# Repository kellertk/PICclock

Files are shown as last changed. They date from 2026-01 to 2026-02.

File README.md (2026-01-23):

# PICclock

Variable-frequency clock generator using PIC16F18344 hardware NCO.

See [src/README.md](src/README.md) and [hardware/README.md](hardware/README.md) for details.

## Features

- 1 Hz to 1 MHz output with 50% duty cycle
- Hardware NCO for 12+ Hz (zero CPU overhead)
- Software timing for 1-11 Hz
- Logarithmic frequency sweep via potentiometer
- Step mode for single pulses

## Building

1. Run the configure script:
   - Windows: `.\configure.ps1`
   - Linux/macOS: `./configure`

2. Build: `make`

3. Flash: `make flash`

## Requirements

- Microchip XC8 compiler
- MPLAB X IDE (for IPE and DFP)
- PICkit 5 (or compatible programmer)
- PIC16F1xxxx_DFP device family pack

## License

This project is intentionally available under a restrictive license: CC BY-NC-SA.
Commercial use of this work is not permitted without prior agreement. Please contact
me if you need alternate licensing terms. See [LICENSE.txt](LICENSE.txt) for details.

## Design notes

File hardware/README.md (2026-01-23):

# PICclock Hardware

## Overview

**Architecture:**
```
                          ACTIVE CLOCK OUTPUT
                                  ^
                                  |
                          +-------+-------+
                          |U3: EL7232CNZ  |
                          | Line Driver   |
                          +-------+-------+
                                  |
                          +-------+-------+
                          |U2: 74HC00     |
                          | (VAR/HS MUX)  |
                          +---+-------+---+
                              |       |
                +-------------+       +-------------+
                |                                   |
        VARIABLE CLOCK                        HIGH-SPEED
        (PIC RB6 NCO output)                  OSCILLATOR
                |                                (Y2)
          +-----+-----+
          |   PIC     |
          |   U1      |
          +-----+-----+
           |  |  |  |  |
       [POT][BTN][SW1][SW2]
```

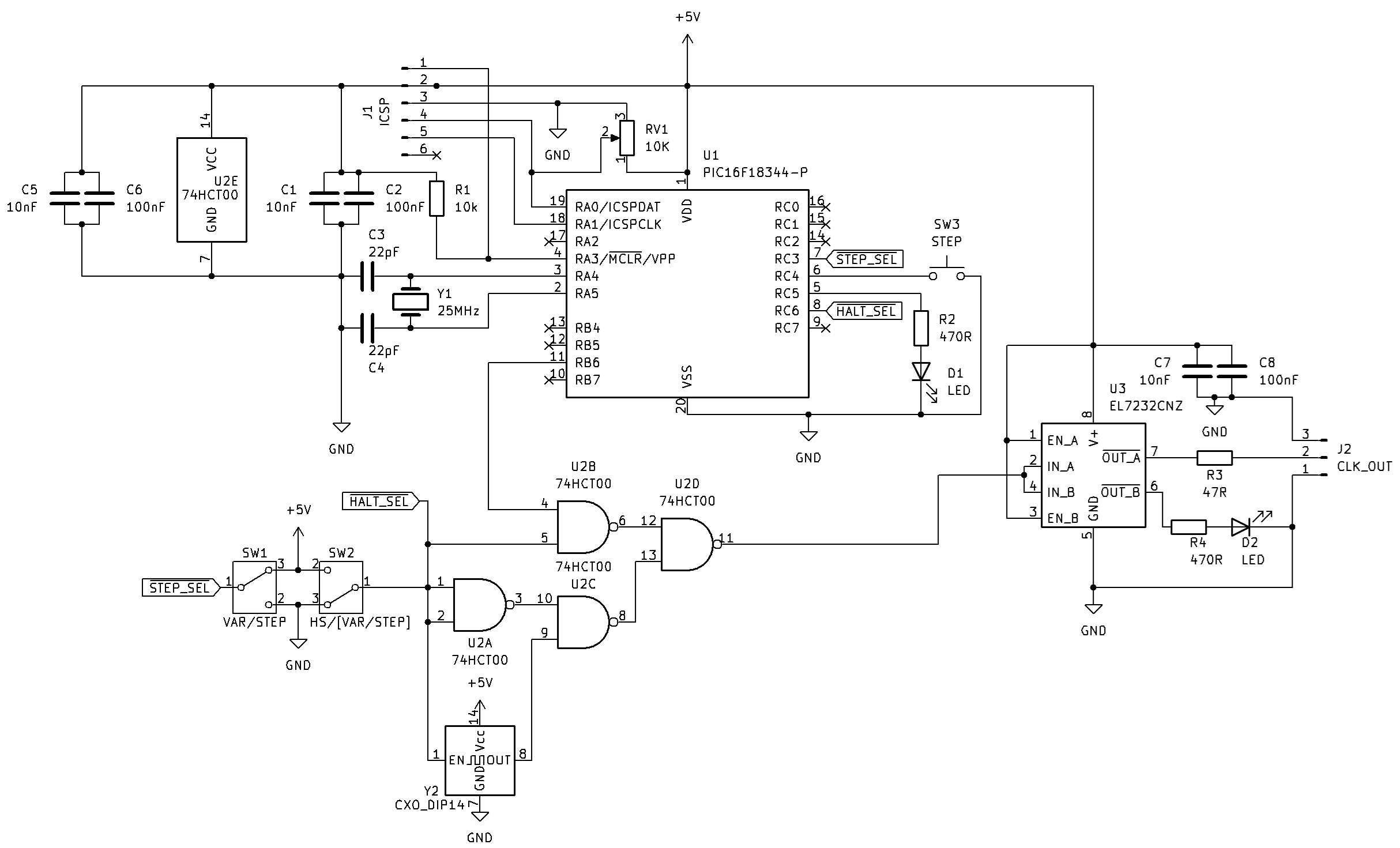
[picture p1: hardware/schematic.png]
PICclock Schematic


**Clock Modes:**
- **Variable**: Hybrid NCO/software clock from PIC (1 Hz - 1 MHz), 50% duty cycle
- **Step**: Single pulse per button press (handled by PIC, debounced in software)
- **High-Speed**: External oscillator bypass

**Frequency Control:** PIC reads potentiometer via ADC. Hardware NCO generates clock for 12 Hz - 1 MHz; software timing handles 1 Hz - 11 Hz. Frequency accuracy inherits PIC crystal stability (typically ±50 ppm).

**Output Driver:** EL7232CNZ line driver buffers clock output.

**Variable Frequency Range:** 1 Hz to 1 MHz (hybrid NCO/software, 50% duty cycle)

---

## Components

### ICs

| Ref | Part | Function |
|-----|---|---|
| U1 | PIC16F18344-I/P | Clock generation (NCO + software timing) |
| U2 | 74HC00 | Quad NAND (var/HS mux) |
| U3 | EL7232CNZ | Line driver |

### Oscillators

| Ref | Part | Function |
|-----|---|---|
| Y1 | 24 MHz crystal | PIC clock |
| Y2 | Oscillator module (w/enable) | High-speed clock (user-selected frequency) |

### Switches & Controls

| Ref | Part | Function |
|-----|---|---|
| SW1 | SPDT slide | Variable/Step select |
| SW2 | SPDT slide | Variable/High-Speed select |
| SW3 | Pushbutton (NO) | Step pulse trigger |
| VR1 | 10K pot | Frequency control |

### Passive Components

| Ref | Value | Function |
|-----|---|---|
| C1 | 10nF | U1 bypass |
| C2 | 100nF | U1 bypass |
| C3, C4 | 22pF | Y1 load caps |
| C5 | 10nF | U2 bypass |
| C6 | 100nF | U2 bypass |
| C7 | 10nF | U3 bypass |
| C8 | 100nF | U3 bypass |
| R1 | 10K | MCLR pull-up |
| R2 | 330Ω | Debug LED current limit |
| R3 | 47Ω | Clock output series resistor |
| R4 | 470Ω | Clock LED current limit |
| LED1 | LED | Debug indicator |
| LED2 | LED | Clock indicator |

---

## Signal Reference

| Signal | Description |
|---|---|
| VAR_CLK | Variable clock from PIC (RB6 NCO1), active low |
| HS_CLK | High-speed external oscillator |
| STEP_SEL | Step mode select (SW1, active low = step) |
| HALT_SEL | High-speed mode select (SW2, active low = high-speed) |
| CLK_OUT | Final clock output (from U3) |

---

## U1: PIC16F18344-I/P (DIP-20)

```
                    +------------+
              VDD --|1         20|-- VSS (GND)
         RA5/OSC1 --|2         19|-- RA0/AN0 <-- VR1 (POT)
         RA4/OSC2 --|3         18|-- RA1/ICSPCLK
     MCLR/VPP/RA3 --|4         17|-- RA2 -x
DEBUG_LED <-- RC5 --|5         16|-- RC0 -x
      SW3 --> RC4 --|6         15|-- RC1 -x
      SW1 --> RC3 --|7         14|-- RC2 -x
      SW2 --> RC6 --|8         13|-- RB4 -x
           x- RC7 --|9         12|-- RB5 -x
           x- RB7 --|10        11|-- RB6 --> VAR_CLK
                    +------------+
```

| Pin | Name | Signal | To |
|-----|---|---|----|
| 1 | VDD | +5V | +5V, J1-2 |
| 2 | RA5/OSC1 | XTAL | Y1, C1 |
| 3 | RA4/OSC2 | XTAL | Y1, C2 |
| 4 | MCLR/VPP/RA3 | MCLR | +5V via R1, J1-1 |
| 5 | RC5 | DEBUG_LED | LED, current limit resistor to GND |
| 6 | RC4 | STEP_BTN | SW3 (internal pull-up) |
| 7 | RC3 | STEP_SEL | SW1 common |
| 8 | RC6 | HALT_SEL | SW2 common |
| 9 | RC7 | - | nc |
| 10 | RB7 | - | nc |
| 11 | RB6 | VAR_CLK | U2-4 (mux input) |
| 12 | RB5 | - | nc |
| 13 | RB4 | - | nc |
| 14 | RC2 | - | nc |
| 15 | RC1 | - | nc |
| 16 | RC0 | - | nc |
| 17 | RA2 | - | nc |
| 18 | RA1 | ICSPCLK | J1-5 |
| 19 | RA0/AN0 | POT | VR1 wiper, J1-4 (ICSPDAT) |
| 20 | VSS | GND | GND, J1-3 |

---

## U2: 74HC00

```
74HC00 (DIP-14)
       +-------+
    1A-|1    14|-VCC
    1B-|2    13|-4B
    1Y-|3    12|-4A
    2A-|4    11|-4Y
    2B-|5    10|-3B
    2Y-|6     9|-3A
   GND-|7     8|-3Y
       +-------+
```

| Pin | Signal | To |
|-----|---|----|
| 1 | 1A | SW2 |
| 2 | 1B | SW2 |
| 3 | 1Y | S̄ → U2-10 |
| 4 | 2A | VAR_CLK (from U1-11, PIC RB6) |
| 5 | 2B | SW2 |
| 6 | 2Y | U2-12 |
| 7 | GND | GND |
| 8 | 3Y | U2-13 |
| 9 | 3A | HS_CLK (from Y2-3) |
| 10 | 3B | U2-3 (S̄) |
| 11 | 4Y | MUX_OUT → U3-2 (line driver input) |

**Mux Truth Table:**

| SW2 | Output |
|-----|---|
| GND (low) | HS_CLK (high-speed oscillator) |
| +5V (high) | VAR_CLK (PIC NCO/software clock or step pulse) |

---

## U3: EL7232CNZ Line Driver

Dual inverting line driver with 3-state outputs. Enable pins are active high.

```
EL7232CNZ (DIP-8)
        +-------+
    ENA-|1     8|-V+
   A IN-|2     7|-A OUT
    ENB-|3     6|-B OUT
   B IN-|4     5|-GND
        +-------+
```

| Pin | Signal | To |
|-----|---|----|
| 1 | ENA | +5V (always enabled) |
| 2 | A IN | MUX_OUT (from U2-11), U3-4 |
| 3 | ENB | +5V (always enabled) |
| 4 | B IN | U3-2 (A IN) |
| 5 | GND | GND |
| 6 | B OUT | LED2 anode, R4 to GND |
| 7 | A OUT | R3 → J2-1 |
| 8 | V+ | +5V |

**Note:** Inverting driver. Channel A drives clock output. Channel B mirrors channel A to drive clock indicator LED.

## Y2: High-Speed Oscillator Module

Standard 4-pin metal can oscillator with active-low enable.

```
     +---------+
     |   Y2    |
     | OSC CAN |
     +---------+
      1  2  3  4
      |  |  |  |
    /EN GND OUT VCC
      |      |   |
     SW2   U2-9 +5V
```

| Pin | Signal | To |
|-----|---|----|
| 1 | /EN | SW2 common (active low) |
| 2 | GND | GND |
| 3 | OUT | HS_CLK → U2-9 |
| 4 | VCC | +5V |

When SW2=GND (halt/HS mode): oscillator enabled, outputs HS_CLK.  
When SW2=+5V (run mode): oscillator disabled, PIC generates clock.

## SW1: SPDT Slide Switch (Variable/Step Select)

```
SW1 (Variable/Step):
  +5V ──[1]
           ├── STEP_SEL → U1-7 (PIC RC3)
  GND ──[2]
```

- **Position 1 (+5V):** Variable mode - PIC generates continuous clock based on pot
- **Position 2 (GND):** Step mode - PIC waits for button press, outputs single pulse

---

## SW2: SPDT Slide Switch (Variable/High-Speed Select)

```
SW2 (Var / High-Speed):
  +5V ──[1]
           ├──┬── HALT_SEL → U1-8 (PIC RC6)
  GND ──[2]   ├── SEL   → U2-1, U2-2, U2-5
              └── /EN   → Y2-1 (oscillator enable, active low)
```

- **Position 1 (+5V):** Variable/Step mode - PIC generates clock, Y2 disabled
- **Position 2 (GND):** High-speed mode - PIC halted, Y2 enabled

---

## SW3: Step Button

Normally-open momentary pushbutton. PIC internal pull-up enabled, debounced in software.

```
U1-6 (PIC RC4) ──┬── [SW3] ── GND
                  │
            (internal pull-up)
```

In step mode (SW1=low), pressing SW3 causes PIC to output a single clock pulse.

---

| 1 | MCLR/VPP | U1-4 (RA3), R1 to +5V |
| 2 | VDD | +5V |
| 3 | VSS | GND |
| 4 | ICSPDAT | U1-19 (RA0) |
| 5 | ICSPCLK | U1-18 (RA1) |

---

## J2: Clock Output (1x2)

| Pin | Signal | To |
|-----|---|----|
| 1 | CLK_OUT | R3 ← U3-7 (EL7232 A OUT) |

## BOM

### ICs
| Ref | Part | Package | Qty |
|-----|---|---|-----|
| U1 | PIC16F18344-I/P | DIP-20 | 1 |
| U2 | 74HC00 | DIP-14 | 1 |
| U3 | EL7232CNZ | DIP-8 | 1 |
| U4 | LM3914 | DIP-18 | 1 |
| Q1 | 2N7000 | TO-92 | 1 |
| Y2 | Oscillator module | DIP-8/14 | 1 |

### Crystal & Capacitors
| Ref | Value | Qty | Function |
|-----|---|-----|---|
| Y1 | 24 MHz | 1 | PIC crystal |
| C1, C2 | 22pF | 2 | Y1 load caps |
| C3, C4, C5, C6 | 100nF | 4 | Decoupling |

### Resistors
| Ref | Value | Qty | Function |
|-----|---|-----|---|
| R1 | 10K | 1 | MCLR pull-up |

### Switches & Controls
| Ref | Part | Qty | Function |
|-----|---|-----|---|
| VR1 | 10K pot | 1 | Frequency control |
| SW1 | SPDT slide | 1 | Var/Step select |
| SW2 | SPDT slide | 1 | (Var+Step)/HS select |
| SW3 | Pushbutton NO | 1 | Step trigger |

### Connectors
| Ref | Part | Qty | Function |
|-----|---|-----|---|
| J1 | 1x5 header | 1 | ICSP |
| J2 | 1x2 header | 1 | Clock output |

---

## Data Flow

### Variable Clock Mode (SW1=+5V, SW2=+5V):
1. Y2 oscillator disabled (/EN=high)
2. PIC sees HALT_SEL=high on RC6, STEP_SEL=high on RC3
3. PIC reads potentiometer on AN0
4. PIC generates clock on RB6 using NCO (≥12 Hz) or software timing (<12 Hz)
5. U2 NAND mux passes VAR_CLK
6. U3 line driver buffers output
7. CLK_OUT = hybrid NCO/software clock (1 Hz to 1 MHz)

### Step Mode (SW1=GND, SW2=+5V):
1. Y2 oscillator disabled (/EN=high)
2. PIC sees HALT_SEL=high on RC6, STEP_SEL=low on RC3
3. PIC waits for button press on RC4 (debounced in software)
4. On press: PIC outputs single pulse on RB6
5. U2 mux passes pulse to output
6. CLK_OUT = single step pulse

### High-Speed Mode (SW2=GND):
1. Y2 oscillator enabled (/EN=low)
2. PIC sees HALT_SEL=low on RC6, holds RB6 low, LED off
3. U2 mux selects HS_CLK
4. U3 line driver buffers output
5. CLK_OUT = high-speed oscillator frequency
6. SW1 position ignored

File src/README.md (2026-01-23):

# PICclock Firmware Design

## Overview

Generates a variable-frequency clock output using a hybrid NCO/software approach.  
Output range: 1 Hz to 1 MHz on RB6 with 50% duty cycle.

**Timing Methods:**
- **NCO mode (12 Hz - 1 MHz):** Hardware NCO generates clock with zero CPU overhead
- **Software mode (1 Hz - 11 Hz):** Delay loops for sub-NCO frequencies

Frequency accuracy inherits from the PIC's 24 MHz crystal (typically ±50 ppm).

## Hardware Interface

| Function | Pin  | Description |
|---|---|---|
| Crystal | RA4/5| 24 MHz external crystal |
| ADC Input | RA0  | Potentiometer (0-5V) |
| Clock Output | RB6  | NCO1 output, active low (drives EL7232CNZ) |
| Debug LED | RC5  | Status indicator |
| Halt Select | RC6  | High-speed mode (SW2, active low) |
| Step Button | RC4  | Step pulse trigger (SW3) |
| Step Select | RC3  | Step mode select (SW1, active low) |
| ICSP | RA0/1| Programming interface |

## Timing Analysis

PIC16F18344 @ 24 MHz:
- NCO clock = Fosc = 24 MHz
- NCO resolution = 20 bits (2^20 = 1,048,576)

**NCO Frequency Formula:**
```
F_out = (Fosc × NCO_INC) / 2^21
F_out = (24,000,000 × NCO_INC) / 2,097,152
```

**NCO Increment Range:**

| NCO_INC | Frequency |
|---|---|
| 1 | 11.4 Hz |
| 87,381  | 1 MHz |

**Software Mode Formula:**
```
F_out = Fosc / (2 × half_period_cycles)
F_out = 24,000,000 / (2 × half_period)
```

## Modules

### main.c

Application entry point with hybrid clock generation.

| Function | Purpose |
|---|---|
| `adc_init` | Configure AN0 with Fosc/64 clock |
| `adc_read` | Return 8-bit ADC result |
| `nco_init` | Configure NCO1 for FDC mode output |
| `nco_set_increment`| Update NCO frequency |
| `nco_connect` | Route NCO1 to RB6 via PPS |
| `nco_disconnect` | Disconnect NCO, use GPIO |
| `nco_stop` | Disable NCO output |
| `output_step_pulse`| Generate single step pulse |
| `button_pressed` | Debounced button read |
| `main` | Mode detection and clock generation  |

### freq_table.h

Combined lookup table mapping ADC values (0-255) to frequency settings.

| Data | Purpose |
|---|---|
| `freq_table[]` | 256 entries: software half-periods or NCO increments |

Bit 31 indicates mode:
- Bit 31 = 1: Software mode, bits 0-23 = half-period in cycles
- Bit 31 = 0: NCO mode, bits 0-19 = NCO increment value

Logarithmically spaced (1 Hz to 1 MHz) for perceptually uniform control feel.

## Main Loop

1. Check mode switches (active low):
   - RC6 (Halt): Hold output low, LED off
   - RC3 (Step): Wait for button, output single pulse
2. If resuming from halt/step:
   - Re-read ADC and reconfigure mode
3. If software mode (freq < 12 Hz):
   - Generate clock with delay loops
   - Check for mode/frequency changes during delays
4. If NCO mode (freq ≥12 Hz):
   - NCO runs autonomously
   - Poll ADC for frequency changes

## Configuration Bits

| Setting | Value | Reason |
|---|---|---|
| FOSC | HS | 24 MHz external crystal |
| WDTE | OFF | No watchdog needed |
| PWRTE | OFF | Power-up timer disabled |
| BOREN | ON | Brown-out protection |
| CP | OFF | No code protection |

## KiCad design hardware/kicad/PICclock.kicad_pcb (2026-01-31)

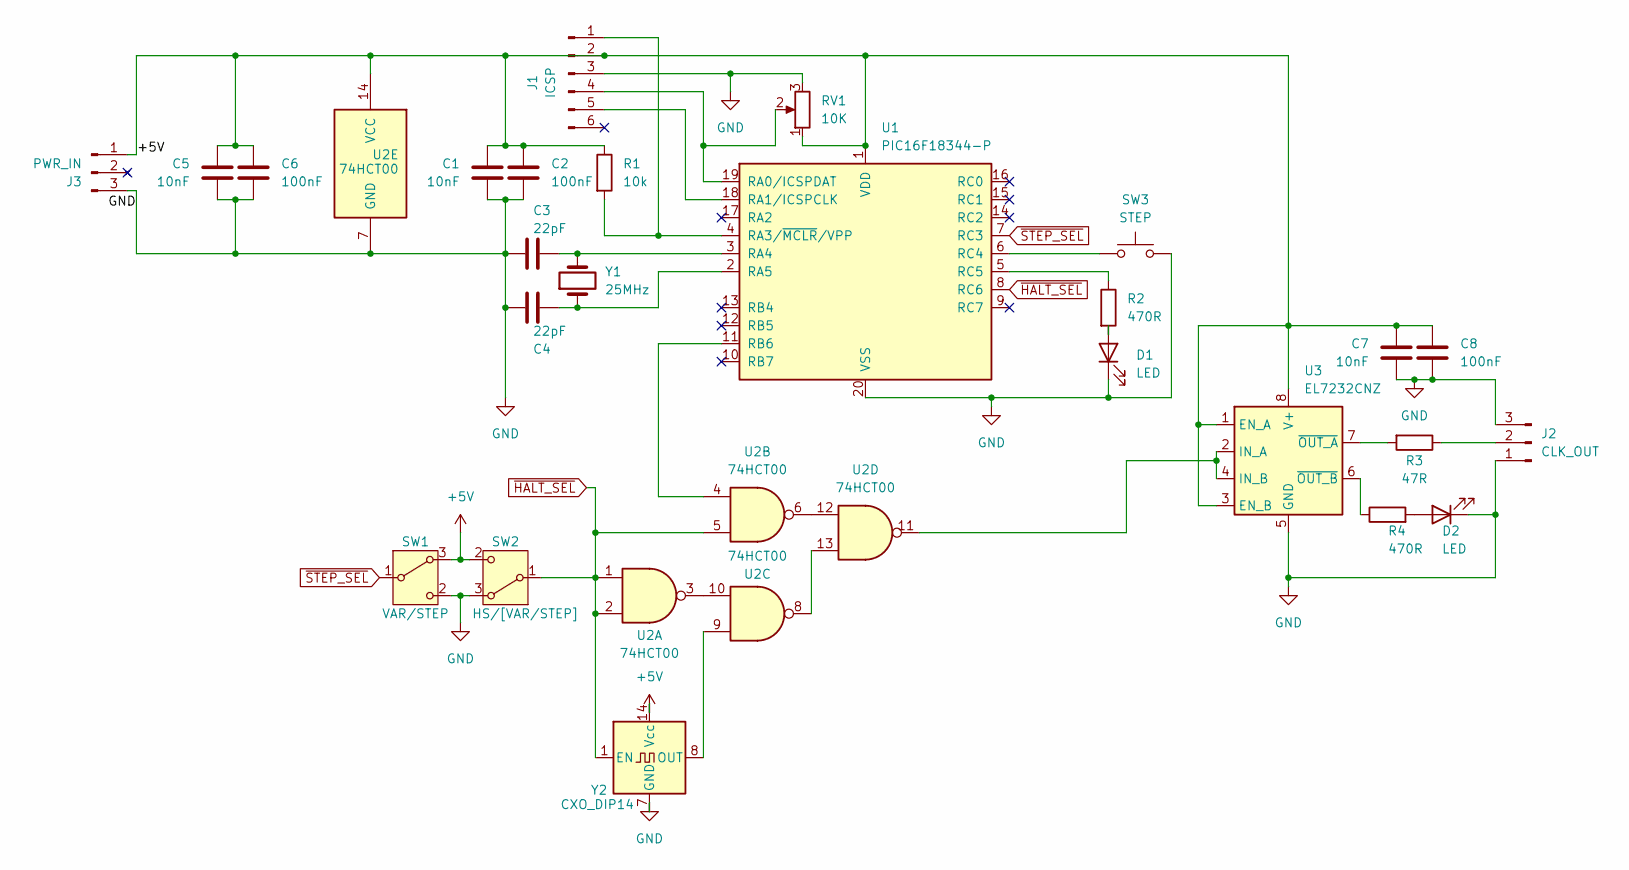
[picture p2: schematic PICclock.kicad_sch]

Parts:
C1, C5, C7: 10nF; C_Disc_D6.0mm_W2.5mm_P5.00mm
C2, C6, C8: 100nF; C_Disc_D6.0mm_W2.5mm_P5.00mm
C3, C4: 22pF; C_Disc_D6.0mm_W2.5mm_P5.00mm
D1, D2: LED; LED_D3.0mm_FlatTop
J1: ICSP; PinSocket_1x06_P2.54mm_Vertical
J2: CLK_OUT; PinHeader_1x03_P2.54mm_Vertical
J3: PWR_IN; PinHeader_1x03_P2.54mm_Vertical
R1: 10k; R_Axial_DIN0207_L6.3mm_D2.5mm_P10.16mm_Horizontal
R2, R4: 470R; R_Axial_DIN0207_L6.3mm_D2.5mm_P10.16mm_Horizontal
R3: 47R; R_Axial_DIN0207_L6.3mm_D2.5mm_P10.16mm_Horizontal
RV1: 10K; Potentiometer_Bourns_3339P_Vertical
SW1: VAR/STEP; SW_Slide-03_Wuerth-WS-SLTV_10x2.5x6.4_P2.54mm
SW2: HS/[VAR/STEP]; SW_Slide-03_Wuerth-WS-SLTV_10x2.5x6.4_P2.54mm
SW3: STEP; SW_Cherry_MX_1.00u_PCB
U1: PIC16F18344-P; DIP-20_W7.62mm_Socket_LongPads
U2: 74HCT00; DIP-14_W7.62mm_Socket_LongPads
U3: EL7232CNZ; DIP-8_W7.62mm_Socket_LongPads
Y1: 25MHz; Crystal_HC49-U_Vertical
Y2: CXO_DIP14; Oscillator_DIP-14_LargePads

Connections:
+5V: C1.2, C2.1, C5.2, C6.1, C7.2, C8.1, J1.2, J3.1, R1.1, RV1.1, SW1.3 (A), SW2.2 (C), U1.1 (VDD), U2.14 (VCC), U3.1 (EN_A), U3.3 (EN_B), U3.8 (V+), Y2.14 (Vcc)
GND: C1.1, C2.2, C3.1, C4.2, C5.1, C6.2, C7.1, C8.2, D1.1 (K), D2.1 (K), J1.3, J2.1, J2.3, J3.3, RV1.3, SW1.2 (C), SW2.3 (A), SW3.2, U1.20 (VSS), U2.7 (GND), U3.5 (GND), Y2.7 (GND)
unnamed: D1.2 (A), R2.2
unnamed: D2.2 (A), R4.2
unnamed: J1.1, R1.2, U1.4 (RA3/~MCLR/VPP)
unnamed: J1.4, RV1.2, U1.19 (RA0/ICSPDAT)
unnamed: J1.5, U1.18 (RA1/ICSPCLK)
unnamed: J2.2, R3.1
unnamed: C3.2, U1.3 (RA4), Y1.2
unnamed: C4.1, U1.2 (RA5), Y1.1
unnamed: U1.11 (RB6), U2.4
unnamed: SW3.1, U1.6 (RC4)
unnamed: R2.1, U1.5 (RC5)
unnamed: U2.3, U2.10
unnamed: U2.6, U2.12
unnamed: U2.8, U2.13
unnamed: U2.11, U3.2 (IN_A), U3.4 (IN_B)
unnamed: R3.2, U3.7 (~OUT_A)
unnamed: R4.1, U3.6 (~OUT_B)
unnamed: U2.9, Y2.8 (OUT)
~HALT_SEL: SW2.1 (B), U1.8 (RC6), U2.1, U2.2, U2.5, Y2.1 (EN)
~STEP_SEL: SW1.1 (B), U1.7 (RC3)

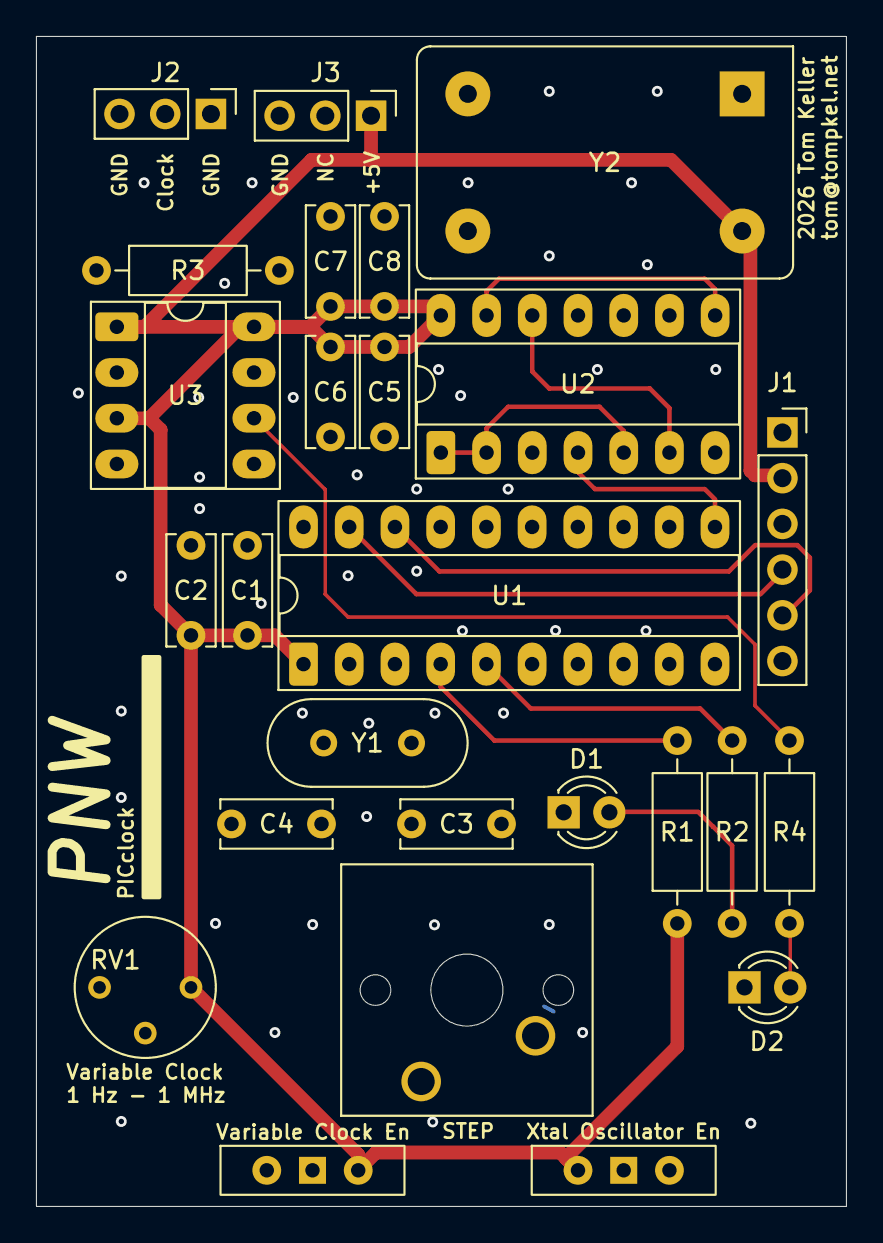
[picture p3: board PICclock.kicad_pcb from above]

Board: 4 copper layers, 45.0 x 65.0 mm, 26 parts (0 on the bottom side), 22 nets.

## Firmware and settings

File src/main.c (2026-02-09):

/**
 * PICclock - Hybrid NCO/Software Clock Generator
 * Target: PIC16F18344 @ 24 MHz (external crystal)
 * 
 * Generates variable-frequency clock output using:
 *   - Hardware NCO for 12 Hz to 1 MHz (zero CPU overhead)
 *   - Software timing for 1 Hz to 11 Hz (trivial overhead at slow speeds)
 * 
 * Output on RB6 drives EL7232CNZ line driver.
 * 
 * Frequency range: 1 Hz to 1 MHz with 50% duty cycle
 * Timing accuracy: Inherits from 24 MHz crystal (typically ±50 ppm)
 * 
 * NCO FDC mode: F_out = (24 MHz × NCO_INC) / 2^21
 */

#include <xc.h>
#include <stdint.h>
#include "freq_table.h"
#include "clc_debounce.h"

// Configuration bits for PIC16F18344
#pragma config FEXTOSC = HS    // External oscillator: HS (24 MHz crystal)
#pragma config RSTOSC = EXT1X  // Power-up oscillator: EXTOSC (no 4x PLL)
#pragma config CLKOUTEN = OFF  // Clock out disabled
#pragma config CSWEN = OFF     // Clock switch disabled
#pragma config FCMEN = OFF     // Fail-safe clock monitor disabled
#pragma config MCLRE = ON      // MCLR pin enabled (RA3)
#pragma config PWRTE = OFF     // Power-up timer disabled
#pragma config WDTE = OFF      // Watchdog disabled
#pragma config LPBOREN = OFF   // Low-power BOR disabled
#pragma config BOREN = ON      // Brown-out reset enabled
#pragma config BORV = LOW      // Brown-out voltage low trip point
#pragma config PPS1WAY = ON    // PPS one-way control
#pragma config STVREN = ON     // Stack overflow reset enabled
#pragma config DEBUG = OFF     // Background debugger disabled
#pragma config LVP = OFF       // Low-voltage programming disabled
#pragma config CP = OFF        // Code protection off

#define _XTAL_FREQ 24000000UL  // 24 MHz external crystal

// Pin 2:  RA5/OSC1 = Crystal
// Pin 3:  RA4/OSC2 = Crystal
// Pin 4:  RA3/MCLR = Reset
// Pin 5:  RC5 = Debug LED output
// Pin 6:  RC4 = Step button (SW3, active low)
// Pin 7:  RC6 = Halt select (SW2, active low)
// Pin 8:  RC3 = Step mode select (SW1, active low)
// Pin 11: RB6 = NCO1 output (drives EL7232CNZ)
// Pin 19: RA0 = ADC input (pot)

#define DEBUG_LED   LATCbits.LATC5   // Debug LED (active high)
#define HALT_SEL    PORTCbits.RC6    // Halt select (SW2)
#define STEP_BTN    CLCDATAbits.MLC1OUT  // Step button (SW3) - HW debounced via 3-CLC
#define STEP_SEL    PORTCbits.RC3    // Step mode select (SW1)

static void adc_init(void) {
    ADCON0 = 0x01;         // AN0 selected, ADC enabled
    ADCON1 = 0x60;         // Left-justified, Fosc/64, Vref = VDD/VSS
    ANSELAbits.ANSA0 = 1;  // RA0 is analog
}

static uint8_t adc_read(void) {
    ADCON0bits.GO_nDONE = 1;
    while (ADCON0bits.GO_nDONE);
    return ADRESH;         // Return upper 8 bits (left-justified)
}

/**
 * Initialize the NCO (Numerically Controlled Oscillator)
 * 
 * FDC mode output frequency = (Fosc × NCO_INC) / 2^21
 */
static void nco_init(void) {
    // Configure RB6 as NCO1 output
    TRISBbits.TRISB6 = 0;       // Output
    ANSELBbits.ANSB6 = 0;       // Digital
    
    // Route NCO1 to RB6 via PPS (Peripheral Pin Select)
    RB6PPS = 0x1D;              // NCO1 output (0x1D per datasheet Table 13-3)
    
    NCO1CON = 0x00;             // Disable NCO while configuring
    NCO1CLK = 0x01;             // Clock source = FOSC (24 MHz external crystal)

    // Set initial value
    NCO1INCU = 0x00;            // Upper bits
    NCO1INCH = 0x00;            // High byte
    NCO1INCL = 0x01;            // Low byte - minimum frequency initially
    
    // Clear accumulator
    NCO1ACCU = 0x00;
    NCO1ACCH = 0x00;
    NCO1ACCL = 0x00;
    
    // Enable NCO in Fixed Duty Cycle (FDC) mode - 50% duty cycle output
    NCO1CON = 0x90;             // N1EN=1, N1PFM=0 (FDC mode), N1POL=1
}

/**
 * Update NCO frequency from 20-bit increment value
 */
static void nco_set_increment(uint32_t inc) {
    // Temporarily disable NCO to update increment atomically
    NCO1CON = 0x00;
    
    NCO1INCL = (uint8_t)(inc & 0xFF);
    NCO1INCH = (uint8_t)((inc >> 8) & 0xFF);
    NCO1INCU = (uint8_t)((inc >> 16) & 0x0F);  // Only 4 bits in upper
    
    NCO1CON = 0x90;  // Enable NCO, FDC mode, inverted
}

/**
 * Stop NCO output (for step mode or halt)
 */
static void nco_stop(void) {
    NCO1CON = 0x00;
    LATBbits.LATB6 = 1;         // Ensure output is high
}

/**
 * Disconnect NCO from pin (for software mode)
 * Sets RB6 as regular GPIO output
 */
static void nco_disconnect(void) {
    NCO1CON = 0x00;
    RB6PPS = 0x00;              // Disconnect NCO from RB6, use LATB6
    LATBbits.LATB6 = 1;
}

/**
 * Reconnect NCO to pin
 */
static void nco_connect(void) {
    RB6PPS = 0x1D;              // Route NCO1 to RB6
    NCO1CON = 0x90;             // Enable NCO, FDC mode, inverted
}

void main(void) {
    // Configure I/O
    // PORTA: RA0=analog in, RA4/RA5=crystal
    TRISA = 0b00110001;         // RA0,RA4,RA5 input (crystal pins), rest output
    ANSELA = 0b00000001;        // Only RA0 is analog
    LATA = 0x00;
    
    // PORTB: RB6=NCO out
    TRISB = 0b00000000;         // All outputs
    ANSELB = 0x00;              // All digital
    LATB = 0x00;
    
    // PORTC: RC3,RC4,RC6 = switch inputs, RC5 = LED out
    TRISC = 0b01011000;         // RC3,RC4,RC6 inputs, rest outputs
    ANSELC = 0x00;              // All digital
    LATC = 0x00;
    
    // Enable weak pull-up on step button
    WPUC = 0b00010000;
    
    // Startup LED blink
    DEBUG_LED = 1;
    __delay_ms(100);
    DEBUG_LED = 0;
    __delay_ms(100);
    DEBUG_LED = 1;

    clc_debounce_init();
    adc_init();
    nco_init();

    // Read initial ADC value
    uint8_t last_adc = adc_read();
    uint32_t freq_entry = freq_table[last_adc];
    uint8_t software_mode = IS_SOFTWARE_MODE(freq_entry) ? 1 : 0;
    uint32_t half_period = 0;  // For software mode (in cycles)
    
    if (software_mode) {
        nco_disconnect();
        half_period = GET_FREQ_VALUE(freq_entry);
    } else {
        nco_set_increment(GET_FREQ_VALUE(freq_entry));
    }
    
    uint8_t running = 1;
    uint8_t halted = 0;

    // Main loop
    while (1) {
        // Check mode switches
        uint8_t mode = (HALT_SEL ? 0 : 2) | (STEP_SEL ? 0 : 1);  // Active low switches
        
        // Halt mode: stop output, LED off
        if (mode & 2) {
            if (!halted) {
                if (software_mode) {
                    LATBbits.LATB6 = 1;
                } else {
                    nco_stop();
                }
                DEBUG_LED = 0;
                halted = 1;
                running = 0;
            }
            __delay_ms(50);
            continue;
        }
        
        // Step mode: output stopped, manual pulses
        if (mode & 1) {
            if (running || !halted) {
                if (!software_mode) {
                    nco_disconnect();
                }
                LATBbits.LATB6 = 1;
                running = 0;
                halted = 1;
            }
            DEBUG_LED = 1;

            // Drive output directly from button state (active low)
            if (STEP_BTN == 0) {
                // Button pressed: drive clock low (inverted output)
                LATBbits.LATB6 = 0;

                // Enforce minimum 10ms pulse width
                __delay_ms(10);

                // Hold low while button remains pressed
                while (STEP_BTN == 0) {
                    uint8_t m = (HALT_SEL ? 0 : 2) | (STEP_SEL ? 0 : 1);
                    if (!(m & 1)) break;
                }

                // Release: drive clock high
                LATBbits.LATB6 = 1;
            }
            continue;
        }
        
        // --- Variable frequency mode ---
        
        // Resume from halt/step mode
        if (halted) {
            // Re-read ADC and reconfigure
            last_adc = adc_read();
            freq_entry = freq_table[last_adc];
            software_mode = IS_SOFTWARE_MODE(freq_entry) ? 1 : 0;
            
            if (software_mode) {
                half_period = GET_FREQ_VALUE(freq_entry);
                // RB6 already disconnected from NCO
            } else {
                nco_connect();
                nco_set_increment(GET_FREQ_VALUE(freq_entry));
            }
            DEBUG_LED = 1;  // LED on when running
            running = 1;
            halted = 0;
        }
        
        // Software mode: generate clock with delays
        if (software_mode) {
            // Low phase
            LATBbits.LATB6 = 0;
            
            // Delay for half period (use 10us chunks for long delays)
            // At 24 MHz, 10us = 240 cycles
            // half_period is in cycles, convert to 10us units
            uint32_t delay_10us = half_period / 240;
            for (uint32_t i = 0; i < delay_10us; i++) {
                __delay_us(10);
                
                // Check for mode change every ~10ms
                if ((i & 0x3FF) == 0) {
                    uint8_t m = (HALT_SEL ? 0 : 2) | (STEP_SEL ? 0 : 1);
                    if (m != 0) {
                        LATBbits.LATB6 = 1;
                        break;  // Exit for loop, main while will catch mode change
                    }
                }
            }
            
            // High phase
            LATBbits.LATB6 = 1;
            
            for (uint32_t i = 0; i < delay_10us; i++) {
                __delay_us(10);
                
                // Check for mode change every ~10ms
                if ((i & 0x3FF) == 0) {
                    uint8_t m = (HALT_SEL ? 0 : 2) | (STEP_SEL ? 0 : 1);
                    if (m != 0) break;  // Exit for loop, main while will catch mode change
                    
                    // Also check ADC during low phase
                    uint8_t adc_val = adc_read();
                    if (adc_val != last_adc) {
                        if (adc_val > last_adc + 1 || adc_val < last_adc - 1) {
                            last_adc = adc_val;
                            freq_entry = freq_table[adc_val];
                            
                            // Check if switching to NCO mode
                            if (!IS_SOFTWARE_MODE(freq_entry)) {
                                software_mode = 0;
                                nco_connect();
                                nco_set_increment(GET_FREQ_VALUE(freq_entry));
                                break;
                            } else {
                                half_period = GET_FREQ_VALUE(freq_entry);
                                delay_10us = half_period / 240;
                            }
                        }
                    }
                }
            }
        } else {
            // NCO mode: just poll ADC occasionally
            uint8_t adc_val = adc_read();
            if (adc_val != last_adc) {
                if (adc_val > last_adc + 1 || adc_val < last_adc - 1) {
                    last_adc = adc_val;
                    freq_entry = freq_table[adc_val];
                    
                    // Check if switching to software mode
                    if (IS_SOFTWARE_MODE(freq_entry)) {
                        software_mode = 1;
                        nco_disconnect();
                        half_period = GET_FREQ_VALUE(freq_entry);
                    } else {
                        nco_set_increment(GET_FREQ_VALUE(freq_entry));
                    }
                }
            }
            
            __delay_ms(20);  // NCO runs independently, just poll UI
        }
    }
}

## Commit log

2026-01-24 add additional via stitching
    [PICclock.kicad_pcb]
2026-01-31 add power input
    [PICclock.kicad_pcb, PICclock.kicad_sch]
2026-02-09 switch to CLC for debounce
